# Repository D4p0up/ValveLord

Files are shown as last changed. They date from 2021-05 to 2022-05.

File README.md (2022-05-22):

# ValveLord
Tube Overdrive schematic and PCB inspired by famous 12AU7 Valvecaster

Design fits into a 1590B case.

Designed with Kicad, Mock-up projected with Freecad 

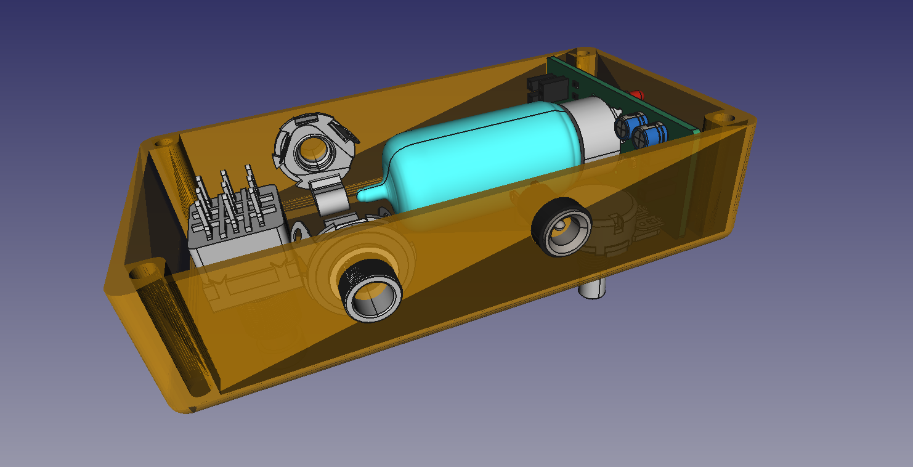
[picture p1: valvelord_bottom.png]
Mech Overview

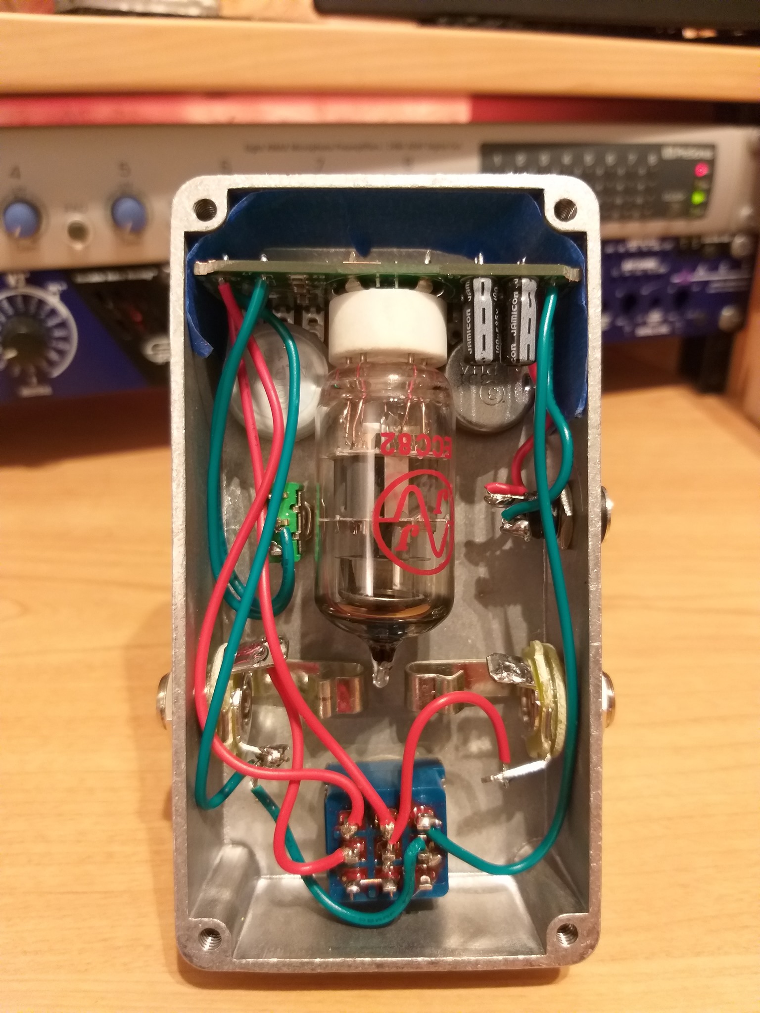
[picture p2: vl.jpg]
vue VL

Schematic SCH
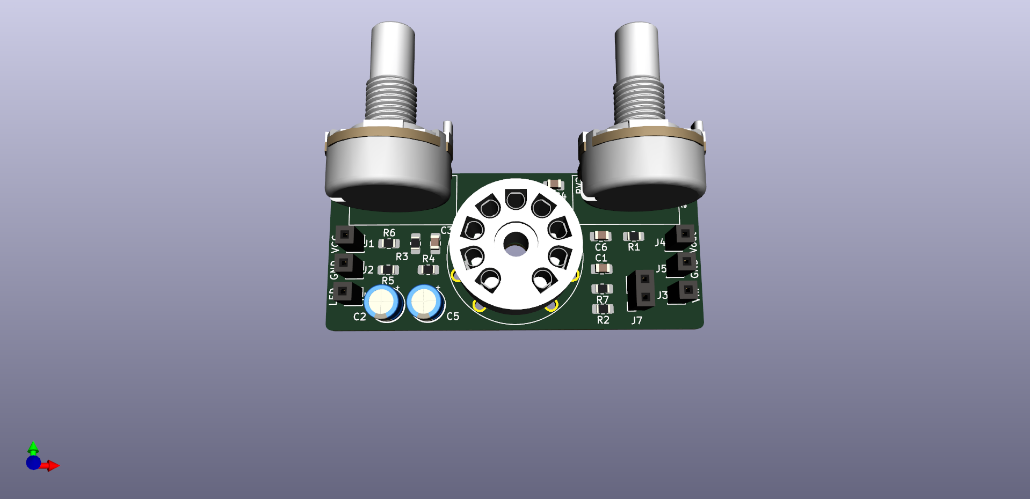
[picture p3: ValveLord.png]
PCB

[demo video](https://github.com/D4p0up/ValveLord/blob/main/2021-05-22%2015-44-17.mp4)

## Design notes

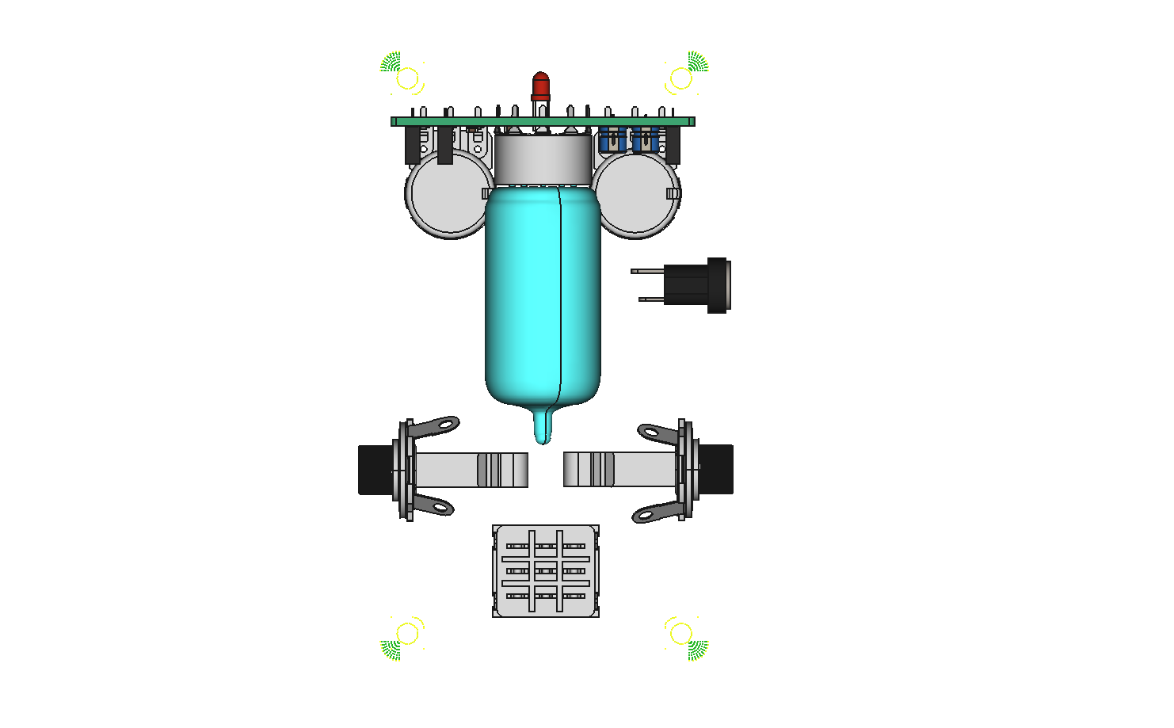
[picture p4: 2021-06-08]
Valvelord MODEL/bottom.png

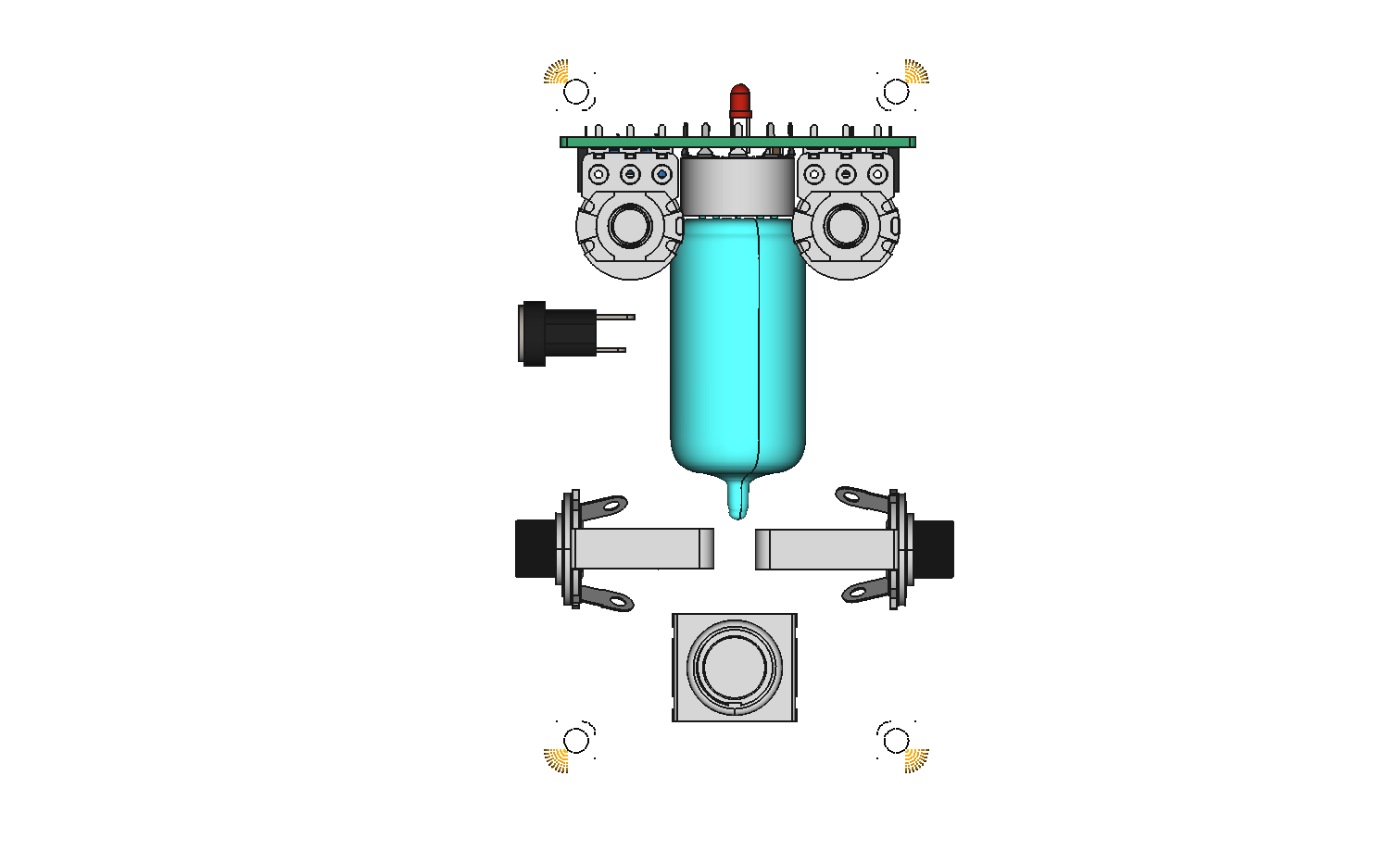
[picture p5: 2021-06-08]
Valvelord MODEL/top.png

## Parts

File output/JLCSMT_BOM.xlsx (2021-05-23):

Comment | Designator | Footprint | LCSC Part #（optional）
47n | C1, C3 | 805 | C53134
1u | C4 | 805 | C28323
2.2n | C6 | 805 | C28260
100k | R2, R4, R7 | 805 | C17407
1M | R1 | 805 | C17514
470k | 470k | 805 | C17709
1k | R6 | 805 | C17513
10R | R5 | 805 | C17415

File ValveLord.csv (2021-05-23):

Reference | Quantity | Value | Footprint | Datasheet | sku | zku
C1 C3 | 2 | 47n | Capacitor_SMD:C_0805_2012Metric_Pad1.18x1.45mm_HandSolder | ~ | C53134
C2 | 1 | 10u | Capacitor_THT:CP_Radial_D5.0mm_P2.50mm | ~
C4 | 1 | 1u | Capacitor_SMD:C_0805_2012Metric_Pad1.18x1.45mm_HandSolder | ~ | C28323
C5 | 1 | 100u | Capacitor_THT:CP_Radial_D5.0mm_P2.50mm | ~
C6 | 1 | 2.2n | Capacitor_SMD:C_0805_2012Metric_Pad1.18x1.45mm_HandSolder | ~ |  | C28260
D1 | 1 | LED | LED_THT:LED_D3.0mm | ~
J1 | 1 | VCC | Connector_PinSocket_2.54mm:PinSocket_1x01_P2.54mm_Vertical | ~
J2 J5 | 2 | GND | Connector_PinSocket_2.54mm:PinSocket_1x01_P2.54mm_Vertical | ~
J3 | 1 | Vin | Connector_PinSocket_2.54mm:PinSocket_1x01_P2.54mm_Vertical | ~
J4 | 1 | Vout | Connector_PinSocket_2.54mm:PinSocket_1x01_P2.54mm_Vertical | ~
J6 | 1 | LED | Connector_PinSocket_2.54mm:PinSocket_1x01_P2.54mm_Vertical | ~
J7 | 1 | Gain | Connector_PinSocket_2.54mm:PinSocket_1x02_P2.54mm_Vertical | ~
R1 | 1 | 1M | Resistor_SMD:R_0805_2012Metric_Pad1.20x1.40mm_HandSolder | ~ | C17514
R2 R4 R7 | 3 | 100k | Resistor_SMD:R_0805_2012Metric_Pad1.20x1.40mm_HandSolder | ~ | C17407
R3 | 1 | 470k | Resistor_SMD:R_0805_2012Metric_Pad1.20x1.40mm_HandSolder | ~ | C17709
R5 | 1 | 10 | Resistor_SMD:R_0805_2012Metric_Pad1.20x1.40mm_HandSolder | ~ | C17415
R6 | 1 | 1k | Resistor_SMD:R_0805_2012Metric_Pad1.20x1.40mm_HandSolder | ~ | C17513
RV1 | 1 | 10kB | Potentiometer_THT:Potentiometer_Piher_T-16H_Single_Horizontal | ~
RV2 | 1 | 100kA | Potentiometer_THT:Potentiometer_Piher_T-16H_Single_Horizontal | ~
U1 | 1 | ECC83 | Valve:Valve_ECC-83-1 | http://www.r-type.org/pdfs/ecc83.pdf

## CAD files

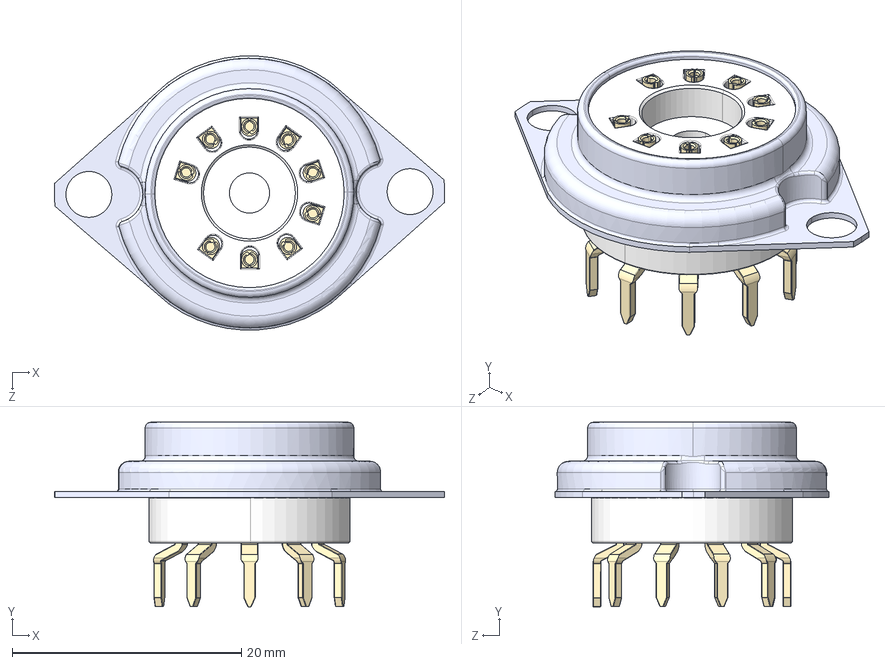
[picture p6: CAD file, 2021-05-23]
assembly_socket_9_pin_vacuum_valve_12ax7_STEP_2.STEP
34.0 x 16.1 x 23.9 mm
socket_base
parte do terminal_superior x 9
terminais_socket_9_pin x 9
suporte_socket_9_pin

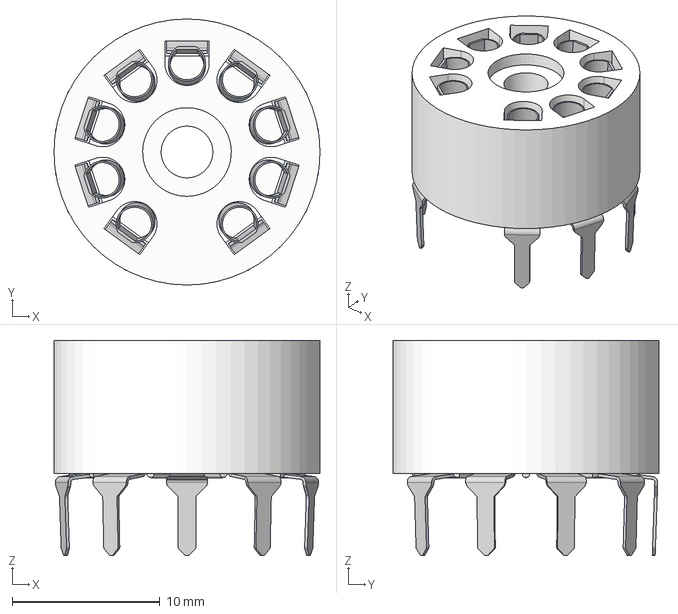
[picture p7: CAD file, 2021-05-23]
Tube Socket - PCB v2.step
18.0 x 18.0 x 14.6 mm

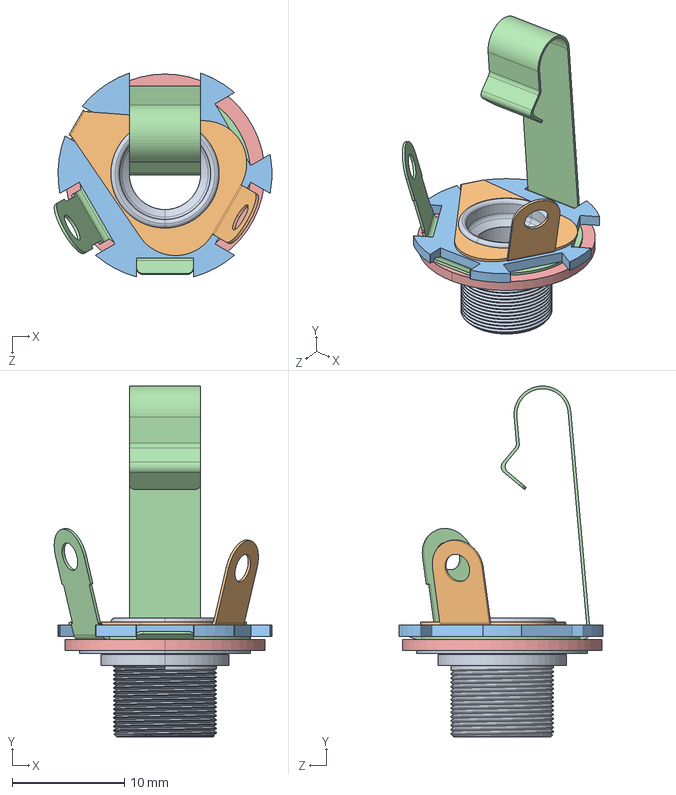
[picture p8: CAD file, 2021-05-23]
Valvelord MODEL/FenderJack.STEP
19.4 x 31.3 x 18.1 mm
FenderJack_Cylinder
FenderJack_UpperTab
FenderJack_UpperSiPlate
FenderJack_LowerTab
FenderJack_LowerSiPlate

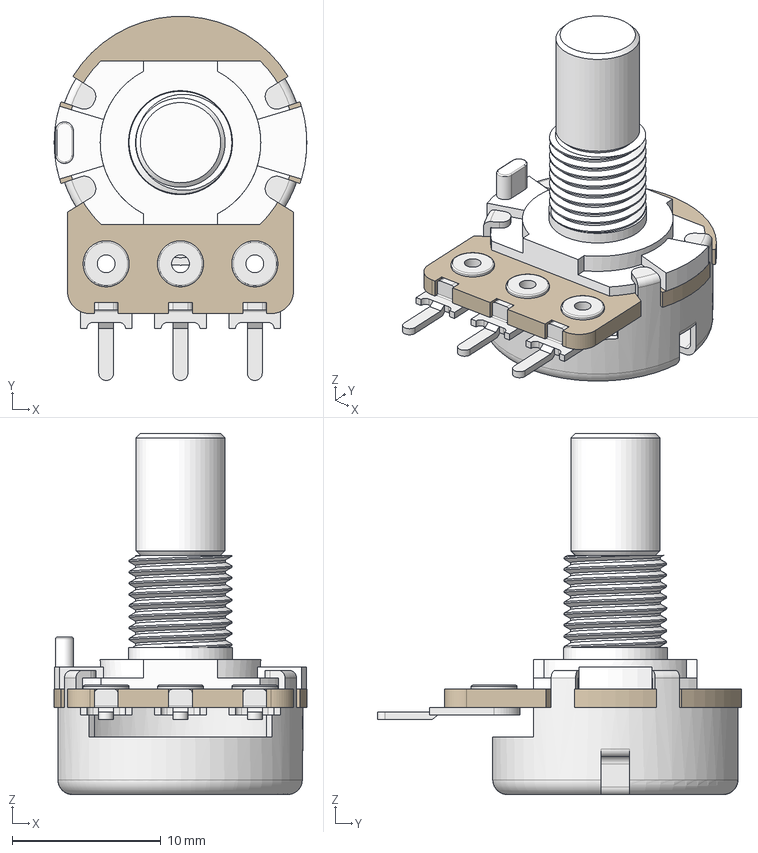
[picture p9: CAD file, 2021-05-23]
RV16AF-20.step
17.0 x 24.5 x 24.3 mm

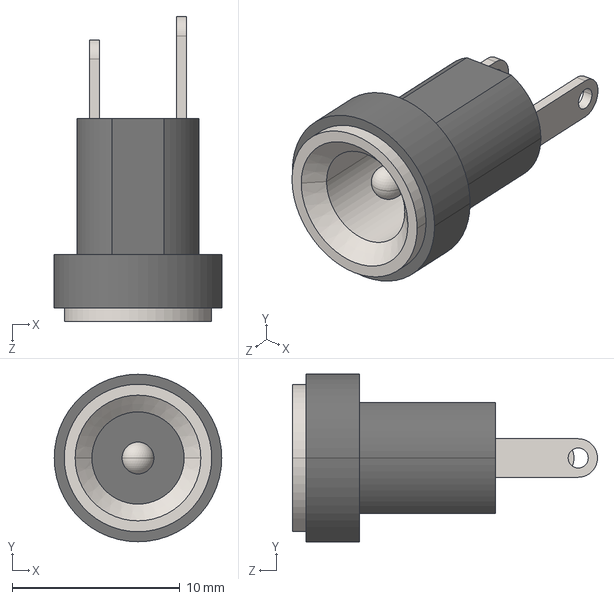
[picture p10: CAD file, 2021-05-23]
Valvelord MODEL/jack.STEP
10.0 x 10.0 x 18.2 mm

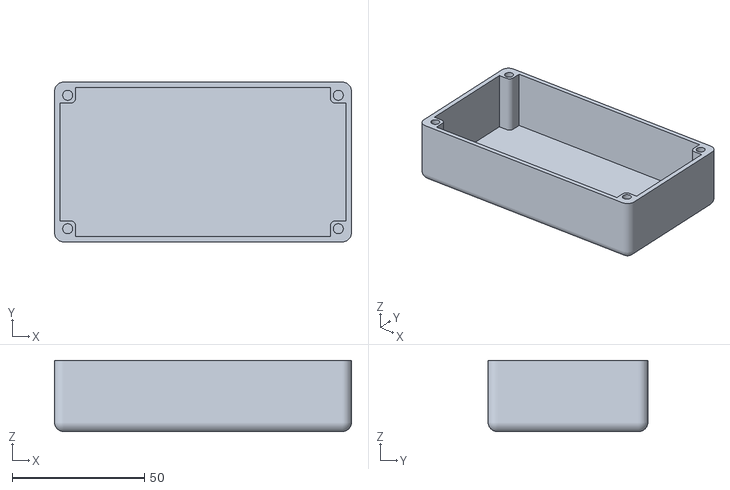
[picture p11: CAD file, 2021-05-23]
parametric_hammond_body20200122-69-11oxp0y.stl
112.4 x 60.5 x 26.9

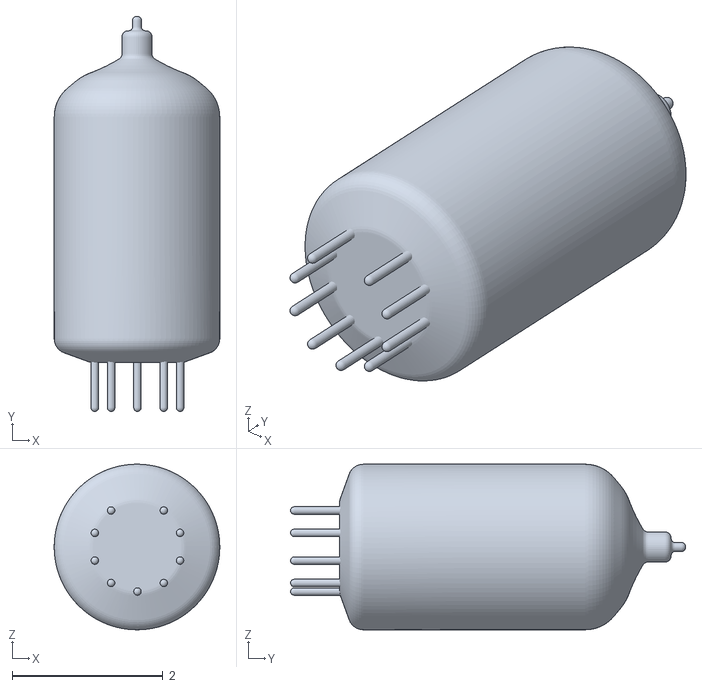
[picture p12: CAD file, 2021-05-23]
12ax7.stl
2.20 x 5.25 x 2.20

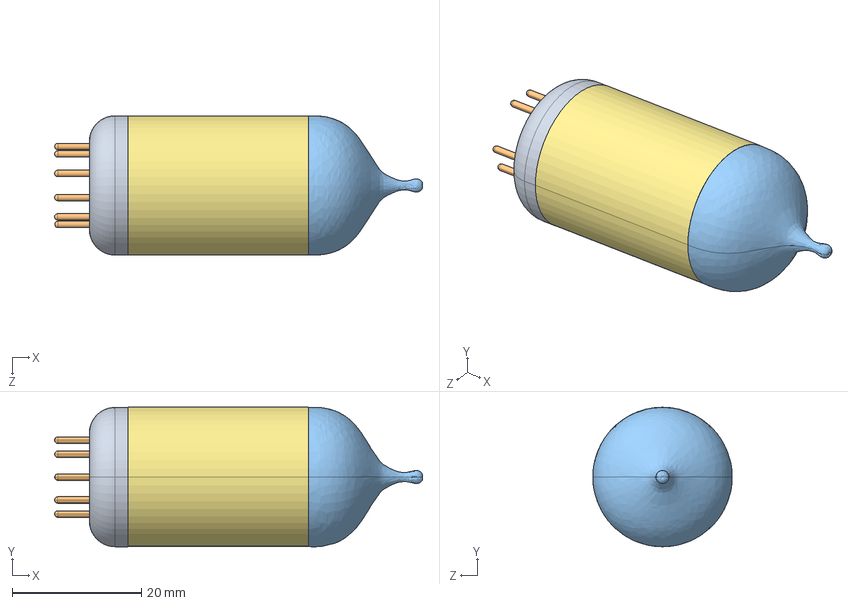
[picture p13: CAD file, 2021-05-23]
final.STEP
56.9 x 21.6 x 21.5 mm
Cópia de chapeu-dissipador^final
suporte-dissipador
dissipador
cintura baixa x 2
coluna-cintura-baixa x 2
anodos x 2
caulda da base
base-vidro-corpo
terminais x 9
corpo-topo
terminais-internos x 3
terminais-lamina
terminais-filamentos x 5
corpo-vidro-meio

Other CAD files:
assembly_socket_9_pin_vacuum_valve_12ax7.STEP
assembly_socket_9_pin_vacuum_valve_12ax7_STEP_AP214.STEP

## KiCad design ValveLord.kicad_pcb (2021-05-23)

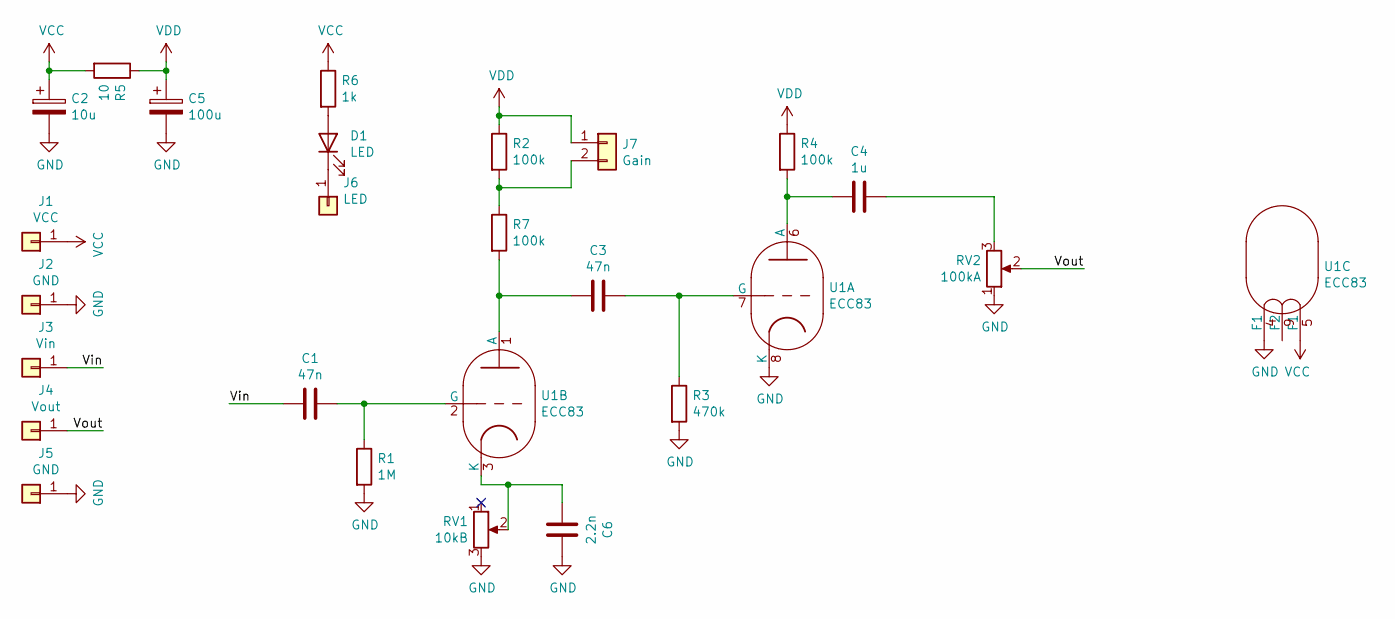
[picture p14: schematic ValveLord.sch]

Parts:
C1, C3: 47n; C_0805_2012Metric_Pad1.18x1.45mm_HandSolder
C2: 10u; CP_Radial_D5.0mm_P2.50mm
C4: 1u; C_0805_2012Metric_Pad1.18x1.45mm_HandSolder
C5: 100u; CP_Radial_D5.0mm_P2.50mm
C6: 2.2n; C_0805_2012Metric_Pad1.18x1.45mm_HandSolder
D1: LED; LED_D3.0mm
J1: VCC; PinSocket_1x01_P2.54mm_Vertical
J2, J5: GND; PinSocket_1x01_P2.54mm_Vertical
J3: Vin; PinSocket_1x01_P2.54mm_Vertical
J4: Vout; PinSocket_1x01_P2.54mm_Vertical
J6: LED; PinSocket_1x01_P2.54mm_Vertical
J7: Gain; PinSocket_1x02_P2.54mm_Vertical
R1: 1M; R_0805_2012Metric_Pad1.20x1.40mm_HandSolder
R2, R4, R7: 100k; R_0805_2012Metric_Pad1.20x1.40mm_HandSolder
R3: 470k; R_0805_2012Metric_Pad1.20x1.40mm_HandSolder
R5: 10; R_0805_2012Metric_Pad1.20x1.40mm_HandSolder
R6: 1k; R_0805_2012Metric_Pad1.20x1.40mm_HandSolder
RV1: 10kB; Potentiometer_Piher_T-16H_Single_Horizontal
RV2: 100kA; Potentiometer_Piher_T-16H_Single_Horizontal
U1: ECC83; Valve_ECC-83-1

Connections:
/Vin: C1.2, J3.1
/Vout: J4.1, RV2.2
GND: C2.2, C5.2, C6.1, J2.1, J5.1, R1.2, R3.2, RV1.3, RV2.1, U1.4 (F1), U1.8 (K)
unnamed: C1.1, R1.1, U1.2 (G)
unnamed: C3.1, R3.1, U1.7 (G)
unnamed: C3.2, R7.2, U1.1 (A)
unnamed: C4.1, RV2.3
unnamed: C4.2, R4.2, U1.6 (A)
unnamed: C6.2, RV1.2, U1.3 (K)
unnamed: D1.1 (K), J6.1
unnamed: D1.2 (A), R6.2
unnamed: J7.2, R2.2, R7.1
VCC: C2.1, J1.1, R5.2, R6.1, U1.5 (F1)
VDD: C5.1, J7.1, R2.1, R4.1, R5.1

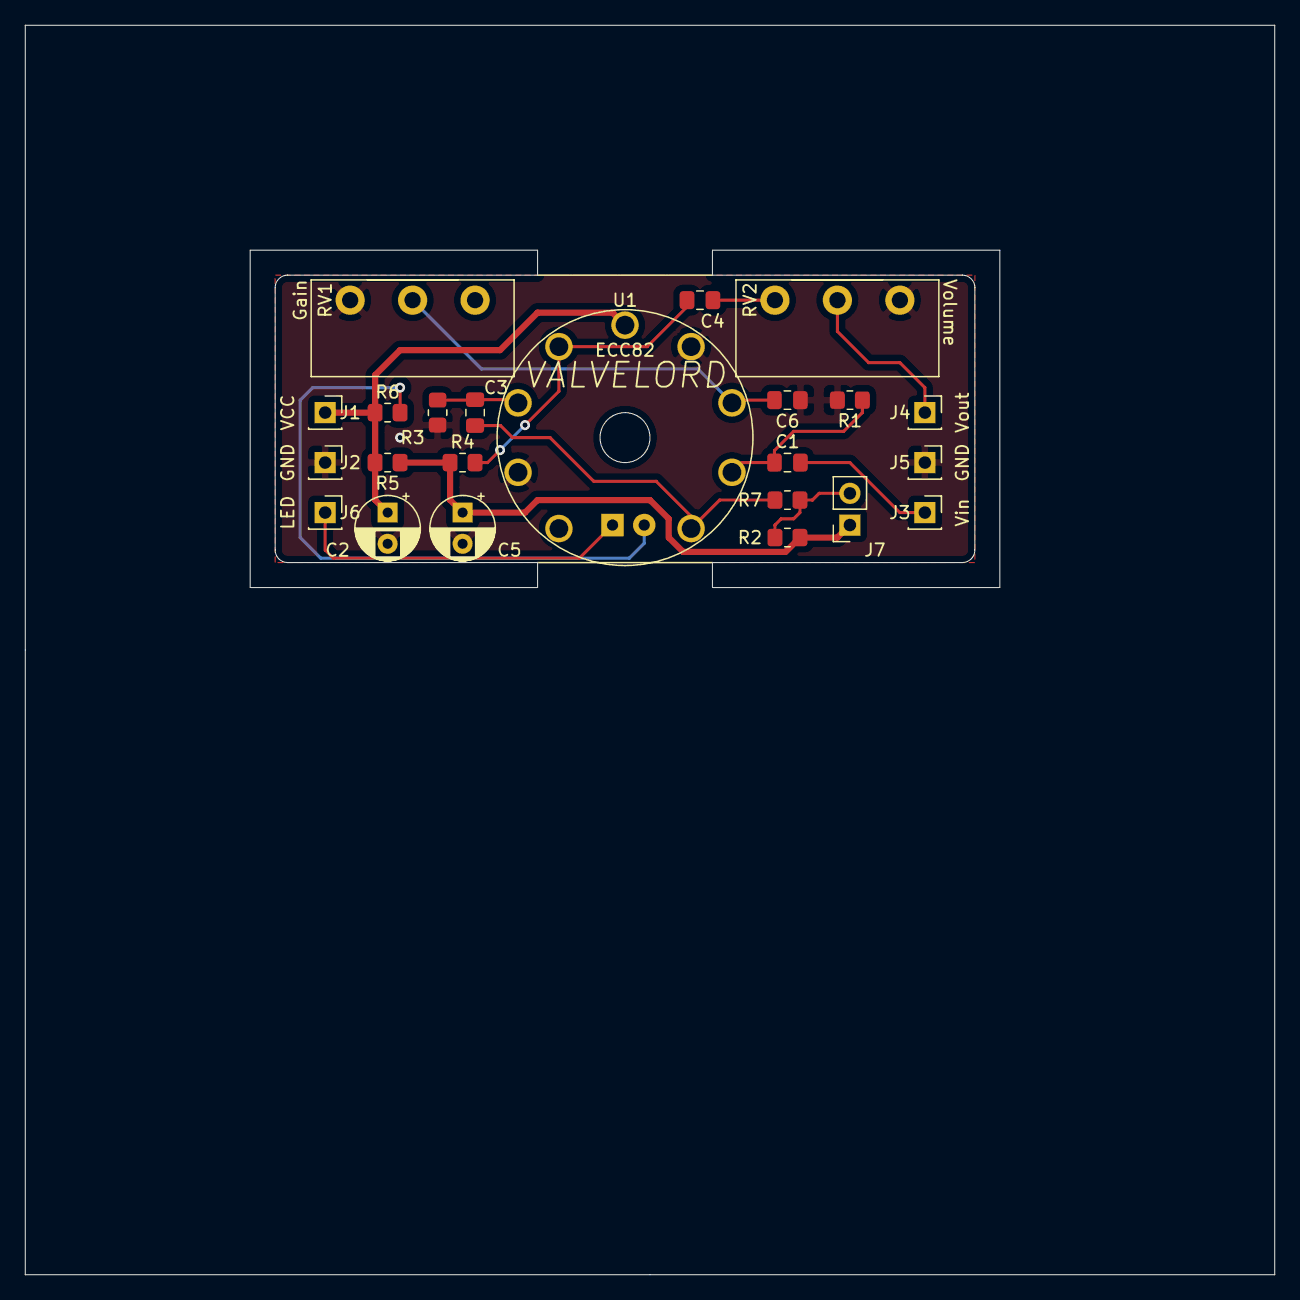
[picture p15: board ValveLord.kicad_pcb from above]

Board: 2 copper layers, 100.0 x 100.0 mm, 24 parts (1 on the bottom side), 14 nets.

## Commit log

2021-05-23 Release 1
    [12ax7.stl, FenderJack.STEP, JLCSMT_BOM.xlsx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]
2021-05-23 Correcting ground Bug
    [ValveLord-B_Cu.gbr, ValveLord-B_Mask.gbr, ValveLord-B_Paste.gbr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]
